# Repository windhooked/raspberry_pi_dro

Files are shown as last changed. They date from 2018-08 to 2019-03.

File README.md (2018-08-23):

# raspberry_pi_dro
Raspberry PI DRO for the Lathe, with Frequency drive control and soft stops

If you ever thought a manual lathe could be more intelligent, and a CNC lathe takes too long to program for one of jobs, this project might be for you. Thread cutting, the cut cycle is slow, the backout cycle is just as painfully slow. It wwoul dbe nice to have a seperate speed for cut and backout cycles.

Features:

1) Simple button controls for forward / Reverse and Stop
2) Set speed on forward and reverse cycles.
3) Soft stops
4) automatic tapping function with depth and reverse out
5) Direct Glass scale interface

Controls:

[ Forward ]        [ Clear ]
[ Reverse ] [Stop] [ Enter ] [ Rotary Enc ]

Functions:
  Fwd <Ent>       " Run forward
  Fwd <Rot> < Ent> " forward with speed adjust
  Rev <Ent>        " Reverse
  Rev <Rot> <Ent>  " Reverse with speed adjust
  Stop             " Stop with break
  
  Stop <Ent>     " Set stop position based  on current Z encoder position, only active when spindle not running
  Stop <Rot> <Ent> " Set stop position with encoder based on current position, only active when spindle is not running
  
  Emergency Stop  " Stop 

Hardware:
The GPIO speed tests I have seen seem fast enough, the problem is if the cpu is busy some steps might get lost. I ahve been wanting to make use of a few HCTL2000 IC's in the parts bin. 

GPIO 3.3V to 5V
          5,6,13,16,19,20,21,26 <- D0-D7
          4  -> CLK 1-4
          23  -> SEL 1 - 4
          24  -> EN 1
          
https://github.com/machinekoder/machinekit-vagrant          
          
abyz.co.uk/rpi/pigpio/code/minimal_clk.zip

https://www.circuitsathome.com/mcu/reading-rotary-encoder-on-arduino
https://www.tansi.org/rp/interfacing5v.html
https://github.com/machinekit
https://github.com/hzeller/rpi-gpio-dma-demo
https://gist.github.com/ast/a19813fce9d34c7240091db11b8190dd

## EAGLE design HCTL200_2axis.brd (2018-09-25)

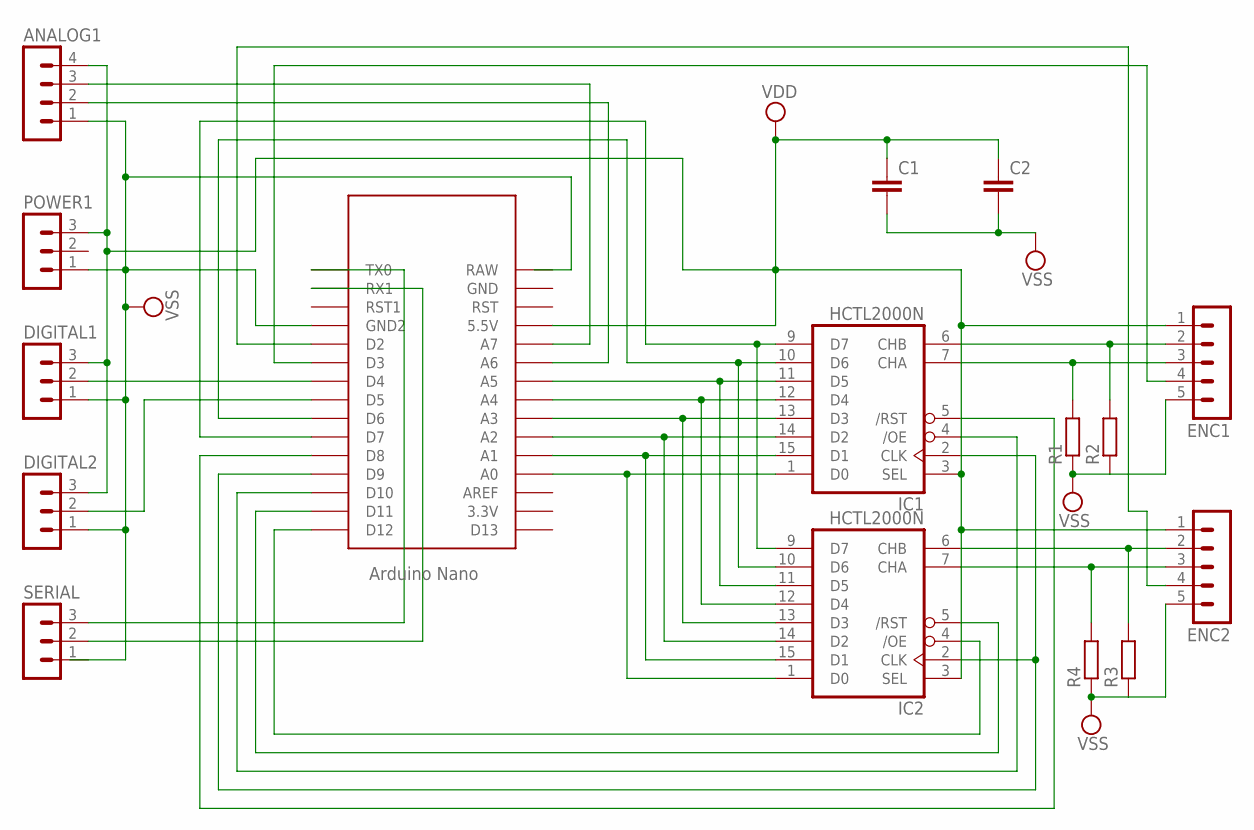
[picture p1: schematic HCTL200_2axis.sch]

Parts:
ANALOG1: MA04-1
C1, C2: C-EU025-030X050; C025-030X050
DIGITAL1, DIGITAL2: MA03-1
ENC1, ENC2: MA05-1
IC1, IC2: HCTL2000N; DIL16
POWER1: MA03-1
R1, R2, R3, R4: R-EU_0204/7; 0204/7
SERIAL: MA03-1
U$1: NANO

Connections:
unnamed: IC1.2 (CLK), IC2.2 (CLK), U$1.D9
unnamed: IC1.5 (/RST), U$1.D8
unnamed: IC1.1 (D0), IC2.1 (D0), U$1.A0
unnamed: IC1.15 (D1), IC2.15 (D1), U$1.A1
unnamed: IC1.14 (D2), IC2.14 (D2), U$1.A2
unnamed: IC1.13 (D3), IC2.13 (D3), U$1.A3
unnamed: IC1.12 (D4), IC2.12 (D4), U$1.A4
unnamed: IC1.11 (D5), IC2.11 (D5), U$1.A5
unnamed: IC1.10 (D6), IC2.10 (D6), U$1.D6
unnamed: IC1.9 (D7), IC2.9 (D7), U$1.D7
unnamed: ENC1.4, U$1.D3
unnamed: ENC1.2, IC1.6 (CHB), R2.2
unnamed: ENC1.3, IC1.7 (CHA), R1.2
unnamed: ENC2.2, IC2.6 (CHB), R3.2
unnamed: ENC2.3, IC2.7 (CHA), R4.2
unnamed: IC2.5 (/RST), U$1.D11
unnamed: IC1.4 (/OE), U$1.D10
unnamed: IC2.4 (/OE), U$1.D12
unnamed: ENC2.4, U$1.D2
unnamed: DIGITAL1.2, U$1.D4
unnamed: DIGITAL2.2, U$1.D5
unnamed: ANALOG1.2, U$1.A6
unnamed: ANALOG1.3, U$1.A7
unnamed: SERIAL.2, U$1.RX1
unnamed: SERIAL.3, U$1.TX0
VDD: ANALOG1.4, C1.1, C2.1, DIGITAL1.3, DIGITAL2.3, ENC1.1, ENC2.1, IC1.3 (SEL), IC1.16 (VDD), IC2.3 (SEL), IC2.16 (VDD), POWER1.3, U$1.5V (5.5V)
VSS: ANALOG1.1, C1.2, C2.2, DIGITAL1.1, DIGITAL2.1, ENC1.5, ENC2.5, IC1.8 (VSS), IC2.8 (VSS), POWER1.1, R1.1, R2.1, R3.1, R4.1, U$1.GND1 (GND2)

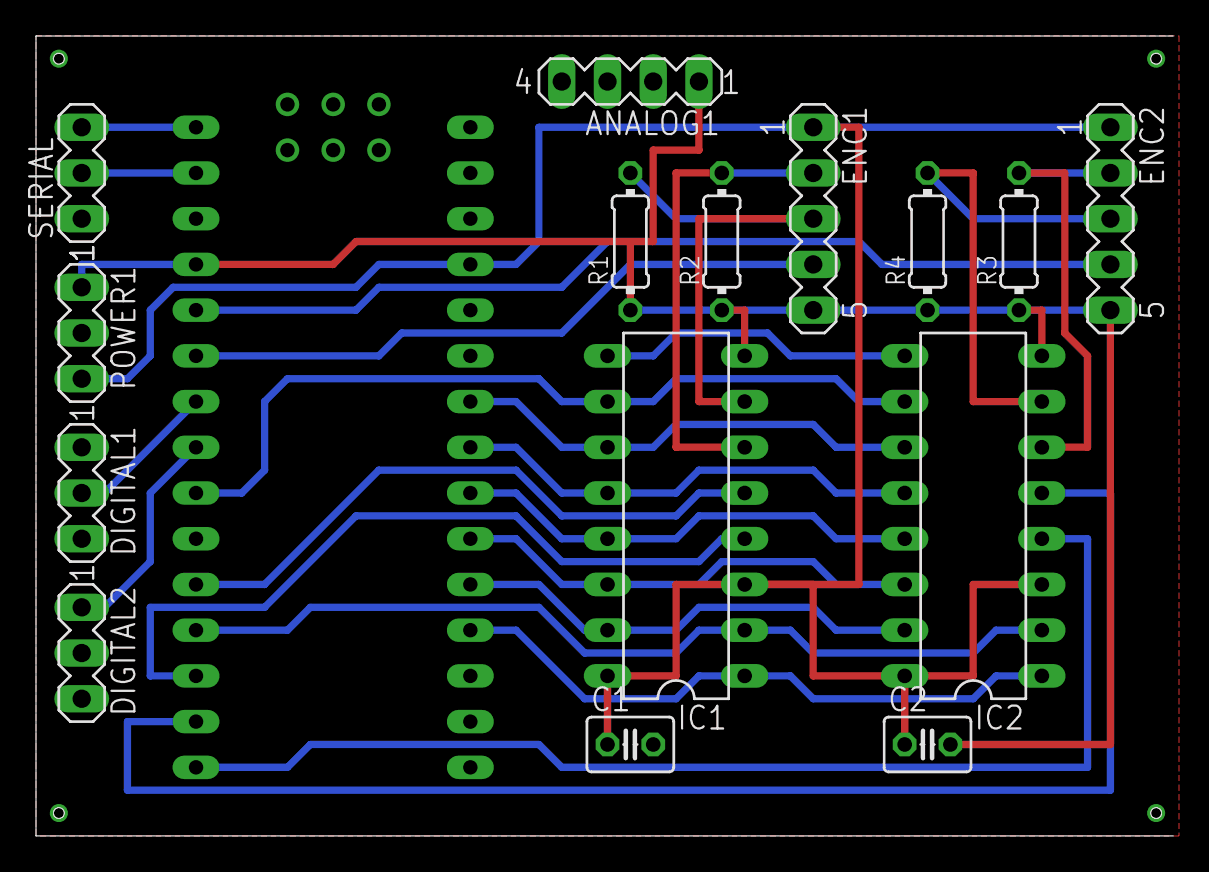
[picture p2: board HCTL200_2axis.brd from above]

Board: 2 copper layers, 63.2 x 44.4 mm, 18 parts (0 on the bottom side), 27 nets.

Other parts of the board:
U$2, U$3: 3,0

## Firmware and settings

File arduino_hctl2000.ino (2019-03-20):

/*
  Simple Lathe Controller based on Arduino Nano and HCTL2000
  
  Author:
  Log:  HdW, Aug 2018 - Draft 1, Tested
  ToDo:   
            
   Limits calculations:
   If the HCTL clock input is 14 MHZ, accordning to the datasheet, the maximum input pulse frequency is 14/3 MHZ or 4,67MHZ
   this equates to 214.3 nS per pulse. 
   If the 8 bit mode (SEL High) is used we can count 127 pulses before counter overflow or 127 * 214 nS = 27.2 uS 
   
   The Arduino port read speed should be faster than 36.7 KHz or at least once every 27.2 uS, using digitalWrite() to 
   select OE will take approximately 8uS. Then for 3 counters this will be 24uS, leaving little margin for other tasks.
    
   For the 12 bit mode, 2048 * 214 nS = 438.9 uS. Here we will also need to toggle the select line for each counter adding 
   another 26uS with the standard digitalWrite. For all three counters OE and SEL in total 52uS. This leaves around 380uS 
   for other tasks. I would like to keep the extra line open for Lathe and VFD Controlls...

   Using direct port writes and reads with ~125ns, per counter would take 500ns for all three 1.5uS
   OE1 = 0;   // 125ns
   read byte D0-5; //125 ns
   read byte D6-7; //125ns
   OE1 = 1;  // 125ns

   conclusion; using direct port reads/writes with the 8 bit mode should leave enough processing time for serial communication,
   calulations and enough free pins for lathe and VFD controlling. 
 
   Feeds are very slow, so no problem there.
   For large lead angle threads like 1 TPI, the carriage would need to travel 25,4mm per rpm
   For a 2000 rpm spindle speed, which is unusualy high for threading, the spindle will rotate 33 times per second, 
   or 838.2mm. Then 838.2/0,005 = 167640 Pulses per second, or 5.9uS per pulse; 
   this is aproximately 30 times slower than the maximum input frequency for the counters.

   Input switches are scanned with oe1-oe3 and swA-swD 
   swA - SwD are mapped to PORTC and have internal pullups resistors enabled. When the input is read on  port C from 
   the external counter the switch status is also read and updated.
   
   PC2 -[]- oe1 

Updates:
 First measurements show read pulses of 125ns
 The read routine is fast enough, but using Arduino Serial.write takes aproximately 650uS per cycle. Will have to convert
 this to an interup driven routine with circular buffer.
 If the spindle runs at 3000 RPM or 50HZ, with a 1000CPR Encoder this will be 50KHz , or 50e3 PPS, still well in limits 
 of 8MHz counter clock.
 
 
For reference, and code snips, ideas, credits are due:

 http://skpang.co.uk/blog/archives/323
 https://efundies.com/avr-bitwise-operations-in-c/
 https://inst.eecs.berkeley.edu/~ee128/fa04/labs/hctl2016.pdf
 http://www.farnell.com/datasheets/312480.pdf
 https://www.torretje.nl/files/p8255optim.ino
 https://arduino.stackexchange.com/questions/16698/arduino-constant-clock-output
 https://www.circuitsathome.com/mcu/reading-rotary-encoder-on-arduino/
 https://forum.arduino.cc/index.php?topic=117964.0
*/
 


#define d2 2 // PD2  14
#define d3 3 // PD3  13
#define d4 4 // PD4  12
#define d5 5 // PD5  11
#define d6 6 // PD6  10
#define d7 7 // PD7  9

#define d0 14 // PC0 1
#define d1 15 // PC1 15

#define swA 16 // PC2
#define swB 17 // PC3
#define swC 18 // PC4 
#define swD 19 // PC5

#define res 8 //PB0 5
#define clk 9 // PB1 2

#define oe1 10 //PB2 4
#define oe2 11 //PB3
#define oe3 12 //PB4
#define xxx 13 //PB5

#define ENC_A 16
#define ENC_B 17
#define ENC_PORT PINC

static int8_t count[3] = {0x0,0x0,0x0}; 
static int8_t count_old[3] = {0x0,0x0,0x0}; 
static uint8_t buttons[3] = {0x0,0x0,0x0}; 
static long  count_position[3] = {0x0,0x0,0x0};

void setup() {     

   pinMode (d0, INPUT); 
   pinMode (d1, INPUT); 
   pinMode (d2, INPUT); 
   pinMode (d3, INPUT); 
   pinMode (d4, INPUT); 
   pinMode (d5, INPUT); 
   pinMode (d6, INPUT); 
   pinMode (d7, INPUT); 
   pinMode (res, OUTPUT); 
   pinMode (clk, OUTPUT); 
   pinMode (oe1, OUTPUT); 

   PORTC =  0b00111100; // pullups for button inputs
  
  digitalWrite(res,LOW);
  digitalWrite(res,HIGH);

  /* Setup encoder pins as inputs */
  pinMode(ENC_A, INPUT);
  digitalWrite(ENC_A, HIGH);
  pinMode(ENC_B, INPUT);
  digitalWrite(ENC_B, HIGH);
  
  // set up 8 MHz timer on CLOCKOUT (OC1A)
  pinMode (clk, OUTPUT); 
  // set up Timer 1
  TCCR1A = bit (COM1A0);  // toggle OC1A on Compare Match
  TCCR1B = bit (WGM12) | bit (CS10);   // CTC, no prescaling
  OCR1A =  0;       // output every cycle
  
  // 
  Serial.begin (115200);
  Serial.println("Start");

}


void readCounters(){
  // enable counter output
   
  PORTB &= ~_BV(2); // Set bit 2 low
//  count[0] = (PIND & 0b11111100) | ( PINC & 0b00000011);
  count[0] = PIND & 0b11111100 
  count[0] |= PINC & 0b00000011;
  buttons[0] = PINC & 0b00111100;
  PORTB |= _BV(2); // Set bit 2 high
  //PORTB &= ~_BV(0); // reset low
  //PORTB |= _BV(0);  // reset high
  
   // enable counter output
 
  PORTB &= ~(1<<3); // Set bit 3 low
  count[1] = (PIND & 0b11111100) | ( PINC & 0b00000011);
  PORTB |= 1<<3; // Set bit 3 high
  //PORTB &= ~_BV(0); // reset low
  //PORTB |= _BV(0);  // reset high
  
   // enable counter output

  PORTB &= ~(1<<4); // Set bit 4 low
  count[2] = (PIND & 0b11111100) | ( PINC & 0b00000011);
  PORTB |= 1<<4; // Set bit 4 high
  PORTB &= ~_BV(0); // reset low
  PORTB |= _BV(0);  // reset high
}

// 
    // should be read every 127 encoder pulses
    // 2048 bits if SEL is used in 12 bit mode 
void updatePosition() {
  
  int delta = 0;
  
  for ( int i = 0; i < 3; i++ ) {
    // if the current count is less the old count are more than 127 bit apart
    
    // then counter overrun error
    // else update position
    
    delta = count[i] - count_old[i]; // get the difference since last run
    //count_old[i] = count[i];
   
   // if ( delta > 127 ){  count[i] = count[i] - 255; } // counter overflow assume one cycle
   // if ( delta < -127){  count[i] = count[i] + 255;  } // counter overflow assume one cycle
    // Serial.println(delta, DEC);
    count_position[i] +=  delta; 
    
  }
   //Serial.println(count_position[0], DEC);
}

 /* returns change in encoder state (-1,0,1) */
int8_t readEncoder()
{
  static int8_t enc_states[] = {0,-1,1,0,1,0,0,-1,-1,0,0,1,0,1,-1,0};
  static uint8_t old_AB = 0;
  /**/
  old_AB <<= 2;                   //remember previous state
  old_AB |= ( ENC_PORT & 0x03 );  //add current state
  return ( enc_states[( old_AB & 0x0f )]);
}

void updateRotEnc(){
  static uint8_t counter = 0;      //this variable will be changed by encoder input
 int8_t tmpdata;
 /**/
  tmpdata = readEncoder();
  if( tmpdata ) {
    Serial.print("Counter value: ");
    Serial.println(counter, DEC);
    counter += tmpdata;
  }
}
void debug() {
   //int var = (PORTD & B11111100) | ( PORTC & B00000011);
   DDRC |= 0x00; 
  int var =  PINC & 0b00000001;
 // var = PORTC & _BV(0)
if (Serial.available() > 0) {
                // read the incoming byte:
               // incomingByte = Serial.read();

                // say what you got:
                Serial.print("in> : ");
                Serial.println(var, HEX);
                pinMode (A0, INPUT);
                Serial.println(digitalRead(A0),HEX);
        }
}
void loop() {
   //  debug();
    readCounters();
    updatePosition();
        
    Serial.print(F("X"));
    Serial.print((long)count_position[0]);
    Serial.println(F(";"));

   // Serial.print(F("Z"));
   // Serial.print((long)position[1]);
   // Serial.println(F(";"));

   // Serial.print(F("T"));
   // Serial.print((unsigned long)position[2]);//tachReadoutMicrosec
   // Serial.print(F("/"));
   // Serial.print((unsigned long)position[2]); // tach position
   // Serial.println(F(";"));
 
  
}

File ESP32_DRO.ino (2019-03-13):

/*

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
 * You should have received a copy of the GNU General Public License
 * along with this program.  If not, see <http://www.gnu.org/licenses/>.
 */
#include <ESP8266WiFi.h>
#include <ESP8266WebServer.h>
#include <DHT.h>
#include <Adafruit_BMP085.h>
#include <FS.h>
#include <TimeLib.h>
#include <NtpClientLib.h>
#include <ArduinoJson.h>

#define ssid      "yourSSID"        // WiFi SSID
#define password  "yourPASSWORD"    // WiFi password
#define DHTTYPE   DHT22             // DHT type (DHT11, DHT22)
#define DHTPIN    D4                // Broche du DHT / DHT Pin
#define HISTORY_FILE "/history.json"
const uint8_t GPIOPIN[4] = {D5,D6,D7,D8};  // Led
int     sizeHist = 84 ;        // Taille historique (7h x 12pts) - History size

const size_t capacity = JSON_OBJECT_SIZE(2) + JSON_OBJECT_SIZE(3) + JSON_OBJECT_SIZE(5);
DynamicJsonBuffer jsonBuffer(capacity);

JsonObject& dro = jsonBuffer.createObject();

JsonObject& disp = dro.createNestedObject("disp");
disp["x"] = 1351824120;
disp["z"] = 1351824120;
disp["s"] = 1351824120;

JsonObject& status = dro.createNestedObject("status");
status["state"] = "ref";
status["mode"] = "lathe";
status["position"] = "abs";
status["tool"] = "T01";
status["base"] = "mm";


const long intervalHist = 1000 * 60 * 5;  // 5 mesures / heure - 5 measures / hours
unsigned long previousMillis = intervalHist;  // Dernier point enregistré dans l'historique - time of last point added

ESP8266WebServer server ( 80 );

StaticJsonBuffer<10000> jsonBuffer;                 // Buffer static contenant le JSON courant - Current JSON static buffer
JsonObject& root = jsonBuffer.createObject();
JsonArray& timestamp = root.createNestedArray("timestamp");
//JsonArray& hist_t = root.createNestedArray("t");
//JsonArray& hist_h = root.createNestedArray("h");
//JsonArray& hist_pa = root.createNestedArray("pa");
//JsonArray& bart = root.createNestedArray("bart");   //  Key histogramm (temp/humidity)
//JsonArray& barh = root.createNestedArray("barh");   //  - Key histogramm (temp/humidity)

char json[10000];                                   // Buffer pour export du JSON - JSON export buffer
/* GPIO endpoint*/
void updateGpio(){

  if (server.hasArg("id")== false || server.hasArg("state")== false ){
     server.send(200, "application/json", "{error: specify GPIO ID and state}");
    return;
  }

  String gpio = server.arg("id");
  String state = server.arg("state");

// int pin = D5;
 if ( gpio == "D5" ) {
      pin = D5;
 } else if ( gpio == "D7" ) {
     pin = D7;
 } else if ( gpio == "D8" ) {
     pin = D8;
 } else {
    server.send(200, "application/json", "{ error: Invalid Pin}");
    return;
 }


  if ( state == "1" ) {
    digitalWrite(pin, HIGH);
  } else if ( state == "0" ) {
    digitalWrite(pin, LOW);
  }

  state = digitalRead(pin);

  String json = "{\"gpio\":\"" + String(gpio) + "\",";
  json += "\"state\":\"" + String(state) ;
  json +=  "\"}";

  server.send(200, "application/json", json);
}
/*
 Return
 disp { k=v, k=v, k=v }, status { state: ref,run,fault; mode: lathe,mill; position: abs,nom,dtg; tool: name;  base: mm,in }

 */
 struct dro {
   float a;
   float b;
   float c;
 } dro_status;

void getDro() {
  String json = "{\"disp\":\"" + String(a)  + "\",";
  json += "\"h\":\"" + String(h) + "\",";
  json += "\"pa\":\"" + String(pa) + "\"}";

  server.send(200, "application/json", json);
  Serial.println("Send measures");
}

void getTools() {
  double temp = root["t"][0];      // Récupère la plus ancienne mesure (temperature) - get oldest record (temperature)
  String json = "[";
  json += "{\"mesure\":\"Température\",\"valeur\":\"" + String(t) + "\",\"unite\":\"°C\",\"glyph\":\"glyphicon-indent-left\",\"precedente\":\"" + String(temp) + "\"},";
  temp = root["h"][0];             // Récupère la plus ancienne mesure (humidite) - get oldest record (humidity)
  json += "{\"mesure\":\"Humidité\",\"valeur\":\"" + String(h) + "\",\"unite\":\"%\",\"glyph\":\"glyphicon-tint\",\"precedente\":\"" + String(temp) + "\"},";
  temp = root["pa"][0];             // Récupère la plus ancienne mesure (pression atmospherique) - get oldest record (Atmospheric Pressure)
  json += "{\"mesure\":\"Pression Atmosphérique\",\"valeur\":\"" + String(pa) + "\",\"unite\":\"mbar\",\"glyph\":\"glyphicon-dashboard\",\"precedente\":\"" + String(temp) + "\"}";
  json += "]";
  server.send(200, "application/json", json);
  Serial.println("Send data tab");
}

void sendHistory(){
  root.printTo(json, sizeof(json));             // Export JSON object as a string
  server.send(200, "application/json", json);   //  Send history data to the web client
  Serial.println("Send History");
}

void loadHistory(){
  File file = SPIFFS.open(HISTORY_FILE, "r");
  if (!file){
    Serial.println("Failed to open history file");
  } else {
    size_t size = file.size();
    if ( size == 0 ) {
      Serial.println("history file empty");
    } else {
      std::unique_ptr<char[]> buf (new char[size]);
      file.readBytes(buf.get(), size);
      JsonObject& root = jsonBuffer.parseObject(buf.get());
      if (!root.success()) {
        Serial.println("Failed to parse json");
      } else {
        Serial.println("History loaded");
        root.prettyPrintTo(Serial);
      }
    }
    file.close();
  }
}

void saveHistory(){
  Serial.println("Save History");
  File historyFile = SPIFFS.open(HISTORY_FILE, "w");
  root.printTo(historyFile); //  Export and save JSON object to SPIFFS area
  historyFile.close();
}

void setup() {

  NTP.onNTPSyncEvent([](NTPSyncEvent_t error) {
    if (error) {
      Serial.print("Time Sync error: ");
      if (error == noResponse)
        Serial.println("NTP server not reachable");
      else if (error == invalidAddress)
        Serial.println("Invalid NTP server address");
      }
    else {
      Serial.print("Got NTP time: ");
      Serial.println(NTP.getTimeDateString(NTP.getLastNTPSync()));
    }
  });
  // Serveur NTP, decalage horaire, heure été - NTP Server, time offset, daylight
  NTP.begin("pool.ntp.org", 0, true);
  NTP.setInterval(60000);
  delay(500);

  for ( int x = 0 ; x < 5 ; x++ ) {
    pinMode(GPIOPIN[x], OUTPUT);
  }

// start reading scale data from Arduino
  Serial.begin ( 115200 );
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

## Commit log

2018-08-25 Update arduino_hctl2000.ino
    First test on breadboard with some pin changes and clock generation with Arduino.
2018-08-25 Update arduino_hctl2000.ino
    Update push button scan logic

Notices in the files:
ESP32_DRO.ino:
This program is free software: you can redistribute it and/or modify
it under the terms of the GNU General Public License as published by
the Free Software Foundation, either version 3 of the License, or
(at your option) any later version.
